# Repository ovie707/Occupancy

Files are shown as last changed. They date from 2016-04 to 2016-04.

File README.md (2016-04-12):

# Occupancy
2015-2016 senior design. 

Occupancy is a system of sensors that can be spread across a building and be analyzed, in our case we are designing it for a college library. These sensory units will be used in order to establish the number of people in each area, and the amount of time they spend in each area. This information can then be used in order to make the library more convenient for students. 

#CO2 Grid-EYE
This code is used on a Tiva Launchpad with a CO2 sensor and a Grid-EYE. The CO2 sensor picks up the amount of CO2 in each area which can be used to establish the amount of people within the area and we can establish the air quality of it. The Grid-EYE is an 8x8 grid of tempurature, and from a top down veiw we can use this in order to establish the number of people in a ten foot area. 

#Occupancy-Testing
Occupancy test v1.1 is the first iteration of having the system 'working.' The central unit sends a remote at command request via it's xbee to the sensor nodes xbee. This raises a pin on the xbee which activates a pin interrupt on the launchpad, which leads to the launchpad reading the data from the sensors, then sending this data back over the xbee to the central unit. See RPi serial format for packet structure

#PCB 
The .brd and .sch files were created using Eagle CS for the Occupancy project. These files will be converted into Gerber files to be sent to a professional fabricator.

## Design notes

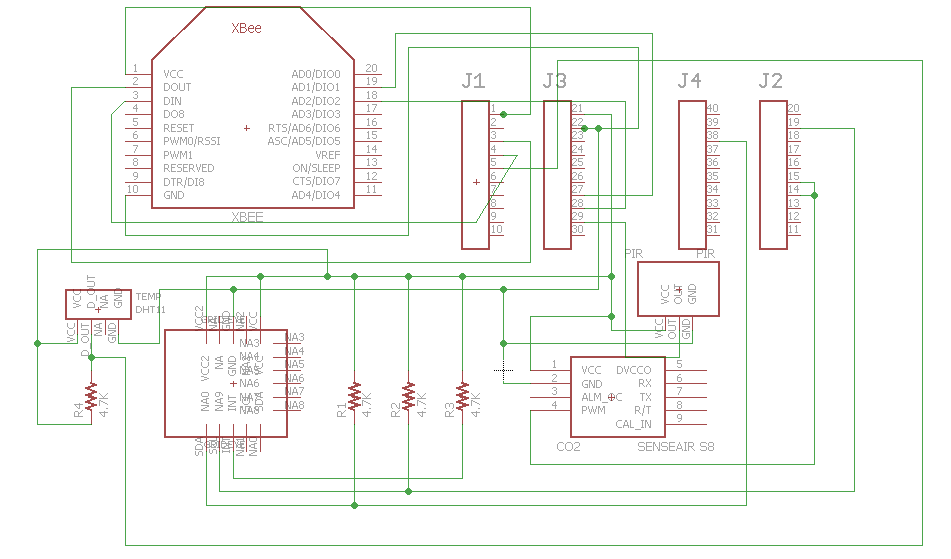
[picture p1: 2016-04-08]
PCB/Occupancy PCB Schematic.PNG

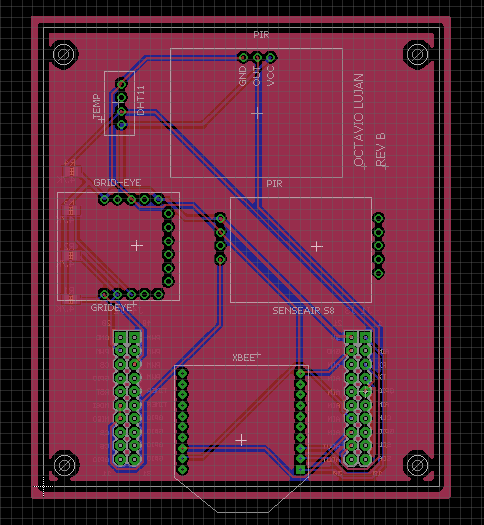
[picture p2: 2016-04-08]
PCB/Occupancy PCB Board.PNG

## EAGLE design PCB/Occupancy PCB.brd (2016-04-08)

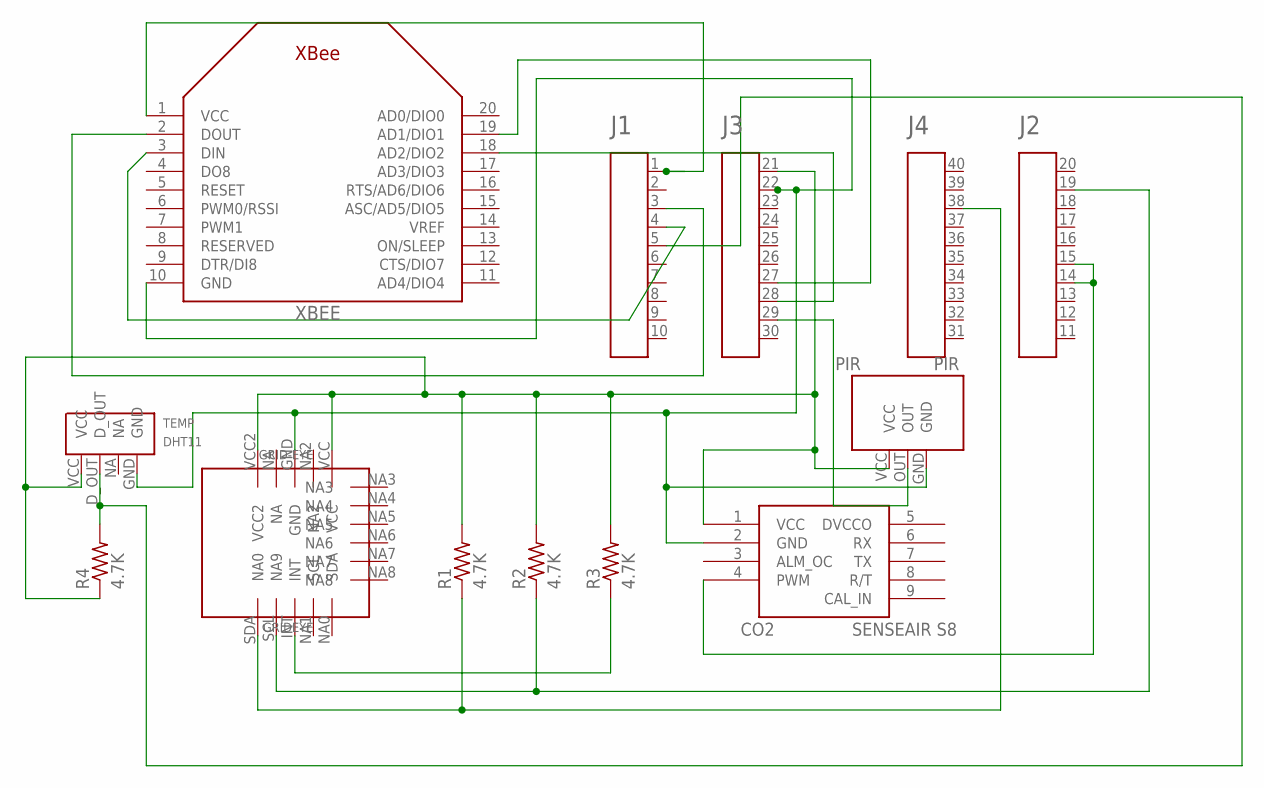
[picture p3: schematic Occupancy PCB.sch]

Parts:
CO2: SENSEAIR-S8-DIP
GRIDEYE: GRID-EYE-DIP
LAUNCHPAD: HEADER4X10-BOOSTERPACK; 4X10-BOOSTERPACK
PIR: PIR-DIP
R1, R2, R3, R4: 4.7K; R0805
TEMP: DHT11-DIP
XBEE: XBEE

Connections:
GND: CO2.2 (GND), GRIDEYE.GND, LAUNCHPAD.22, PIR.GND, TEMP.GND, XBEE.10 (GND)
unnamed: GRIDEYE.SDA (NA0), LAUNCHPAD.38, R1.1
unnamed: CO2.4 (PWM), LAUNCHPAD.14, LAUNCHPAD.15
unnamed: LAUNCHPAD.3, XBEE.2 (DOUT)
unnamed: LAUNCHPAD.4, XBEE.3 (DIN)
unnamed: GRIDEYE.SCL (NA9), LAUNCHPAD.19, R2.1
unnamed: GRIDEYE.INT, R3.1
unnamed: LAUNCHPAD.5, R4.2, TEMP.D_OUT
unnamed: LAUNCHPAD.27, XBEE.19 (AD1/DIO1)
unnamed: LAUNCHPAD.28, XBEE.18 (AD2/DIO2)
unnamed: LAUNCHPAD.29, PIR.OUT
VCC: CO2.1 (VCC), GRIDEYE.VCC, GRIDEYE.VCC2, LAUNCHPAD.21, PIR.VCC, R1.2, R2.2, R3.2, R4.1, TEMP.VCC
VCC3: LAUNCHPAD.1, XBEE.1 (VCC)

Board: 2 copper layers, 10 parts (5 on the bottom side), 13 nets, no tracks yet.

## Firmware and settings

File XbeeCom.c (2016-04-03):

/*
Ovie Onoriose

XbeeComms V1.2.2

Trying out API mode with xBees

Getting the Launchpad to be able to send API transmit requests to a remote xbee.
*/

//includes
#include <stdint.h>
#include <stdio.h>
#include <stdlib.h>
#include <stdbool.h>
#include "inc/tm4c123gh6pm.h"
#include "inc/hw_memmap.h"
#include "inc/hw_types.h"
#include "driverlib/ssi.h"
#include "driverlib/sysctl.h"
#include "driverlib/interrupt.h"
#include "driverlib/gpio.h"
#include "driverlib/timer.h"
#include "driverlib/pin_map.h"
#include "driverlib/uart.h"
#include "utils/uartstdio.h"

//function prototypes
void init_UART(int choice);
void send_packet(void);
void init_timer(void);
void send_grideye_packet(char *data, int data_sum);

//variables
uint8_t ui8PinData=2;
int sys_clock, i;
#define TIMER_FREQ 3
#define UART_BAUDRATE 115200

int main(void)
{
	// Sets the system clock to run using a 16 MHz crystal on the main oscillator to drive the 400 MHz PLL.
	SysCtlClockSet(SYSCTL_SYSDIV_5|SYSCTL_USE_PLL|SYSCTL_XTAL_16MHZ|SYSCTL_OSC_MAIN);
	sys_clock = SysCtlClockGet();

	IntMasterEnable();

	init_timer();
	init_UART(1); //set to 1 for xBee output //set to 0 for Putty output

	// Enables GPIO port F
	SysCtlPeripheralEnable(SYSCTL_PERIPH_GPIOF);
	GPIOPinTypeGPIOOutput(GPIO_PORTF_BASE, GPIO_PIN_1|GPIO_PIN_2|GPIO_PIN_3);

	TimerEnable(TIMER1_BASE, TIMER_A);

	while(1)
	{
//		GPIOPinWrite(GPIO_PORTF_BASE, GPIO_PIN_1|GPIO_PIN_2|GPIO_PIN_3, ui8PinData);
//		SysCtlDelay(2000000);
//		GPIOPinWrite(GPIO_PORTF_BASE, GPIO_PIN_1|GPIO_PIN_2|GPIO_PIN_3, 0x00);
//		SysCtlDelay(2000000);
//		if(ui8PinData==8)
//		{
//			ui8PinData=2;
//		}
//		else
//		{
//			ui8PinData=ui8PinData*2;
//		}
//		UARTprintf("fdgagafdsgsdfg ------- %d -----------\n", j++);
	}
}

void init_timer(void)
{
	// Enable and configure Timer1 peripheral.
	SysCtlPeripheralEnable(SYSCTL_PERIPH_TIMER1);
	// Configure as a 32-bit timer in periodic mode.
	TimerConfigure(TIMER1_BASE, TIMER_CFG_PERIODIC);
	// Initialize timer load register.
	TimerLoadSet(TIMER1_BASE, TIMER_A, sys_clock*TIMER_FREQ -1);
	// Registers a function to be called when the interrupt occurs.
	IntRegister(INT_TIMER1A, send_packet);
	// The specified interrupt is enabled in the interrupt controller.
	IntEnable(INT_TIMER1A);
	// Enable the indicated timer interrupt source.
	TimerIntEnable(TIMER1_BASE, TIMER_TIMA_TIMEOUT);
}

////use this one to output to xBee
//void init_UART(void)
//{
//	//PB0 is input
//	//PB1 is output
//
//	// Enable and configure UART1 for debugging printouts.
//	SysCtlPeripheralEnable(SYSCTL_PERIPH_UART1);
//	SysCtlPeripheralEnable(SYSCTL_PERIPH_GPIOB);
//	GPIOPinConfigure(GPIO_PB0_U1RX);
//	GPIOPinConfigure(GPIO_PB1_U1TX);
//	GPIOPinTypeUART(GPIO_PORTB_BASE, GPIO_PIN_0 | GPIO_PIN_1);
//	UARTStdioConfig(1, UART_BAUDRATE, sys_clock);
//}
//
//
////use this one to output to Putty
//void init_UART(void)
//{
//	// Enable and configure UART0 for debugging printouts.
//	SysCtlPeripheralEnable(SYSCTL_PERIPH_UART0);
//	SysCtlPeripheralEnable(SYSCTL_PERIPH_GPIOA);
//	GPIOPinConfigure(GPIO_PA0_U0RX);
//	GPIOPinConfigure(GPIO_PA1_U0TX);
//	GPIOPinTypeUART(GPIO_PORTA_BASE, (GPIO_PIN_0 | GPIO_PIN_1));
//	UARTStdioConfig(0, UART_BAUDRATE, sys_clock);
//}

void init_UART(int choice)
{
	if (choice == 1)
	{
		//UART outputs using the following pins
		//PB0 is Launchpad input
		//PB1 is Launchpad output
		SysCtlPeripheralEnable(SYSCTL_PERIPH_UART1);
		SysCtlPeripheralEnable(SYSCTL_PERIPH_GPIOB);
		GPIOPinConfigure(GPIO_PB0_U1RX);
		GPIOPinConfigure(GPIO_PB1_U1TX);
		GPIOPinTypeUART(GPIO_PORTB_BASE, GPIO_PIN_0 | GPIO_PIN_1);
		UARTStdioConfig(1, UART_BAUDRATE, sys_clock);
	}
	else
	{
		// UART outputs over USB to Putty
		SysCtlPeripheralEnable(SYSCTL_PERIPH_UART0);
		SysCtlPeripheralEnable(SYSCTL_PERIPH_GPIOA);
		GPIOPinConfigure(GPIO_PA0_U0RX);
		GPIOPinConfigure(GPIO_PA1_U0TX);
		GPIOPinTypeUART(GPIO_PORTA_BASE, (GPIO_PIN_0 | GPIO_PIN_1));
		UARTStdioConfig(0, UART_BAUDRATE, sys_clock);
	}
}

void send_packet(void)
{
	TimerIntClear(TIMER1_BASE, TIMER_TIMA_TIMEOUT);
	GPIOPinWrite(GPIO_PORTF_BASE, GPIO_PIN_1|GPIO_PIN_2|GPIO_PIN_3, ui8PinData);
	SysCtlDelay(1000);
	GPIOPinWrite(GPIO_PORTF_BASE, GPIO_PIN_1|GPIO_PIN_2|GPIO_PIN_3, 0x00);
	//SysCtlDelay(2000000);
	if(ui8PinData==8)
	{
		ui8PinData=2;
	}
	else
	{
		ui8PinData=ui8PinData*2;
	}

	//this packet sends test from coordinator to router
//	char packet[] = {0x7E, 0x00, 0x12, 0x10, 0x01, 0x00, 0x00, 0x00, 0x00, 0x00, 0x00, 0xFF, 0xFF, 0xFF, 0xFE, 0x00, 0x00, 0x74, 0x65, 0x73, 0x74, 0x33};

	//this packet sends test from router to coordinator
//	char packet[] = {0x7E, 0x00, 0x12, 0x10, 0x01, 0x00, 0x00, 0x00, 0x00, 0x00, 0x00, 0x00, 0x00, 0xFF, 0xFE, 0x00, 0x00, 't', 'e', 's', 't', 0x31}; //22 total bytes

//	for(i = 0; i < sizeof(packet); i++)
//		UARTCharPut(UART1_BASE, packet[i]);

	char grideye[] = {5, 5, 5, 5, 5, 5, 5, 5, 5, 5, 5, 5, 5, 5, 5, 5, 5, 5, 5, 5, 5, 5, 5, 5, 5, 5, 5, 5, 5, 5, 5, 5,\
			5, 5, 5, 5, 5, 5, 5, 5, 5, 5, 5, 5, 5, 5, 5, 5, 5, 5, 5, 5, 5, 5, 5, 5, 5, 5, 5, 5, 5, 5, 5, 5,\
			5, 5, 5, 5, 5, 5, 5, 5, 5, 5, 5, 5, 5, 5, 5, 5, 5, 5, 5, 5, 5, 5, 5, 5, 5, 5, 5, 5, 5, 5, 5, 5,\
			5, 5, 5, 5, 5, 5, 5, 5, 5, 5, 5, 5, 5, 5, 5, 5, 5, 5, 5, 5, 5, 5, 5, 5, 5, 5, 5, 5, 5, 5, 5, 5};

//	for(i = 0; i < 128; i++)
//	{
//		UARTCharPut(UART0_BASE, grideye[i]);
//	}

	send_grideye_packet(grideye, 0x1A80);
}

void send_grideye_packet(char *data, int data_sum) //data should be 128 bytes long
{
	//  Data comes in as 128 byte char array (each temp register has a high and a low)
	//	Use code below to parse on receiving end to get full temp value
	//	temp[i] = high byte[i]
	//	temp << 8;    /* redundant on first loop */
	//	temp[i] += low byte[i];

	//	packet needs to contain:
	//	xbee frame stuff 17 bytes
	//	unit identifier 1 byte
	//	data type 1 byte
	//	data 128 bytes for grid eye
	//	terminator 2 bytes (0xDF, 0xDF or 223,223)
	//	xbee frame checksum 1 byte

	//initalizing array to beginning of xbee frame (doesn't include RF data or chksum)
	char packet[150] = {0x7E, 0x00, 0x92, 0x10, 0x00, 0x00, 0x00, 0x00, 0x00, 0x00, 0x00, 0x00, 0x00, 0xFF, 0xFE, 0x00, 0x00};
	int i;

	packet[17] = 0x01; //unit identifier: this unit is #1

	packet[18] = 0x01; //data type: grid eye data is type 1

	//appending RF data into packet
	for(i = 0; i < 128; i++)
	{
		packet[19 + i] = *data;
		data++;
	}

	//RF data terminators for parsing on receiving end
	packet[147] = 0xDF;
	packet[148] = 0xDF;

	//	calculating check sum
	//	xbeeframe data sums up to 0x20E
	//	unit id, data type, and terminator sums to 0x1C0
	//	total sum excluding rf data: 0x3CE
	//	total sum including all 53 rf data: 0x1E4E
	int sum = data_sum + 0x3CE;
	packet[149] = (0xFF - (sum & 0xFF));
	for(i = 0; i < 150; i++)
	{
		UARTCharPut(UART1_BASE,packet[i]);
	}

}

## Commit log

2016-02-29 Create CO2 Grid-EYE
    Code in C that runs on the Tiva Launchpad that runs the CO2 sensor and Grid-EYE.
2016-03-22 Current version of XbeeCom
    This code sends dummy grid eye data (128 bytes) along with a sensor unit identifier, data type and delimeter. This is the format of the packet it sends.
    17 bytes
    These bytes are used by the xBee in API mode.
    0x7E, 0x00, 0x92, 0x10, 0x01, 0x00, 0x00, 0x00, 0x00, 0x00, 0x00, 0x00, 0x00, 0xFF, 0xFE, 0x00, 0x00
    1 byte
    Sensor unit identifier. right now it's just 1, but as we add more units it will go higher
    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
2016-04-03 Create XbeeComms V1-3.c
    This is an updated version of XbeeComms that replaces the timer interrupt with a pin interrupt so that the launchpad can receive data requests periodically. This way the RPi can send data requests to each sensor node at a time to ease up congestion as well as make it easier to stay organized. The RPi will send a remote AT command request to the sensor unit which will cause that units Xbee to set one of it's pins high. This will cause the launchpad to read it's sensor data and send the data back to the RPi. Once the RPi receives the data, it should send a remote AT command to set the pin low, until it's ready for another data sample.
    [XbeeComms V1-3.c]
2016-04-08 PCB Board and Schematic Files
    Contains the .brd and .sch files as well as a .PNG file for both the board and schematic.
    [Occupancy PCB.brd, Occupancy PCB.sch]
2016-04-08 Eagle Part Library
    This library contains the parts used for Rev B of the PCB. Parts include the DHT11, Grid-eye, Senseair S8 CO2, and PIR sensors.
2016-04-08 PCB Board and Schematic Files
    [Occupancy PCB.brd, Occupancy PCB.sch]
